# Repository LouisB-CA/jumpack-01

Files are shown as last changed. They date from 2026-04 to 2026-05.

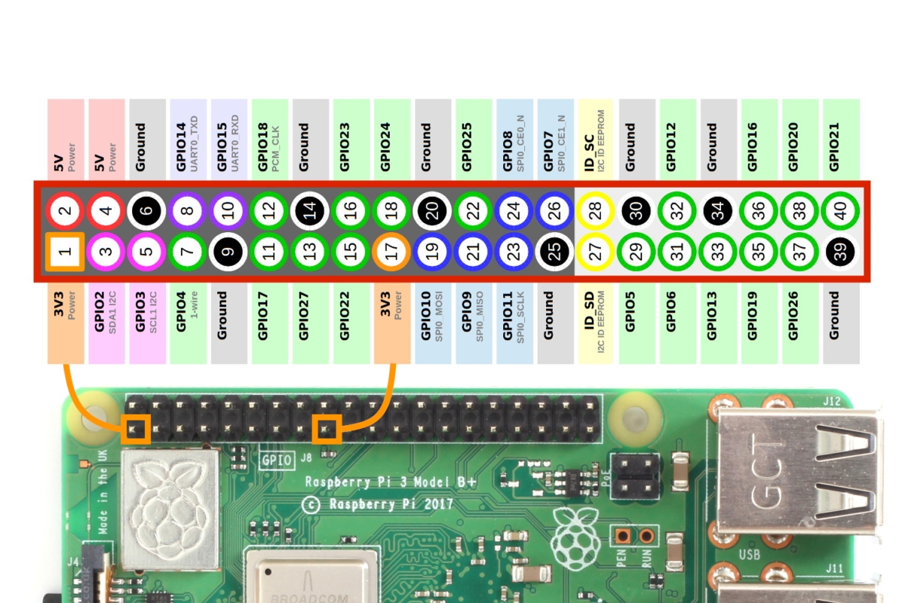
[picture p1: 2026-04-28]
wiring/RPi-GPIO-pinouts-2.png

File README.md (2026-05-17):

# Jumpack-01 battery charger monitor
**Runs on:** [ RPi4, x86 ]

**Languages:** Python, SQL, bash

**Status:** Active

## Hardware Dependencies

| Main Component | Host | Role |
|---|---|---|
| ina228_logger_*.py | RPi4 | polls the sensor, writes SQLite DB |
| monitor-xx.py | x86 | Reads DB, renders real-time plot |

| Support | Host | Role |
|---|---|---|
| simulate_real_time.py | RPi4 | playback |
| dump.py, generate_test_data.py | debugging |

## Description

The INA228 board is used to take 20-bit precision measuements during a battery charging session.
The board communicates with a headless RPi4 via I2C.  

Software is provided to store the data in an SQLite3 database, which can be accessed during the charging operation. 

Software is also provided that can be run from a remote location to plot the data as it is recorded.

The charger is a Coleman lantern wall wart rated at 13.5vdc and 400mA output.

The load is a Cobra Jumpack with input rated at 14vdc and 1A.

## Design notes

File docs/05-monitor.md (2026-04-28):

# How to Monitor the Charging Process

## Rough - needs checking

1. activate the virtual environment - do this as user pi on RPi
2. start the logger in the background - root privileges may be required
3. connect the Coleman power supply and the Jumpack battery
4. create a symlink, charging.db, to the running sqlite3 database
5. on the debian desktop, run 
	`ssh -Y cygnus 'cd ~/prgms/Python/jumpack-01/ && ./.venv/bin/python monitor-02.py'

6. on the RPi, monitor the progress with the *sql_queries.sh* script

## How monitor-02.py works

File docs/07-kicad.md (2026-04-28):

# Version
* The schematic was originally created in KiCad 9.0.7, on 2026-04-26
* At the time, KiCad 10.0.0 was having issues

# Project Library
* All symbols are kept in the project library

# Workflow for KiCad

## Method One uses *sshfs*
* Use a temporary mountpoint on the Debian desktop computer
<br>to mount the remote project directory
```bash
REMOTE="cygnus:prgms/Python/jumpack-01"
MNTPOINT="~/Projects/jumpack"
mkdir -p "$MNTPOINT"
sshfs "$REMOTE" "$MNTPOINT"
```
* Edit the schematic in KiCad on Debian
* Unmount and remove the temporary mountpoint
```bash
# umount usually works, and fuermount3 -u always works
umount "$MNTPOINT"  ||  fusermount3 -u $MNTPOINT"
```

## Method Two uses *git*
* Clone the whole project repo to the Debian desktop computer
* Edit the KiCad schematic
* Commit and push the changes to github

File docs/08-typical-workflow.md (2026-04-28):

# Jumpack-01 battery charger monitor

## In a nutshell
1. Check the wiring
2. Activate the venv
3. Run the ina228 monitor in the background
4. Plug in the charger and the battery
5. Run the monitor program via ssh to plot the data
6. Wait till the current drops to zero

## Typical Workflow
* Do this on the headless RPi4
```bash
PROJECT_DIR="$HOME/prgms/Python/jumpack-01"
cd "$PROJECT_DIR"

source .venv/bin/activate

# Note the use of (1) sudo and (2) the local python
sudo ./.venv/bin/python ina228_logger_v2.py &
```
* Do this on the desktop computer
```bash
ssh -Y cygnus 'cd ~/prgms/Python/jumpack-01/ && python monitor-02.py
```

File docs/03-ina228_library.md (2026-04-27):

# CircuitPython Library for INA228 

* https://docs.circuitpython.org/projects/ina228/en/latest/#
* https://docs.circuitpython.org/projects/ina228/en/stable/index.html

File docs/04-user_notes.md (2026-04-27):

# Workflow
* Activate the virtual environment
* Start the logger program, which must run with root permissions
  <br> `sudo ./.venv/bin/python ./ina228_logger_v2.py &`

* Plug in the Jumpack and the Coleman wall wart

## Options for monitoring the readings
* Include the --verbose flag as an argument to the ina228_logger_v2 python
* Monitor the charging current and voltage with SQL queries
* Use ***waypipe*** to view the plots on a desktop computer
  <br> `waypipe ssh pi@cygnus "cd ~/prgms/Python/jumpack-01 && python monitor-02.py"`

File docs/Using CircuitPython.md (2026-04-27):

Using CircuitPython on a Raspberry Pi 4 requires the [Adafruit Blinka](https://learn.adafruit.com/circuitpython-on-raspberrypi-linux/overview) library, which translates CircuitPython APIs to work on Linux. [1] 
## 1. Pre-requisites
Before running code, you must enable I2C on your Raspberry Pi: [2] 

* Enable I2C: Use the terminal command sudo raspi-config and navigate to Interfacing Options > I2C to enable the bus.
* Install Blinka: Run pip3 install adafruit-blinka to provide the board and busio modules. [1, 3, 4, 5, 6] 

## 2. Basic I2C Scan Example
This "Hello World" of I2C identifies the hexadecimal addresses of all connected devices on the default bus. [7, 8] 

import timeimport board
# Initialize the I2C bus using the board's default SCL and SDA pinsi2c = board.I2C()
while not i2c.try_lock():
    pass
try:
    while True:
        # Scan for devices and print their addresses in hex format
        addresses = [hex(device_address) for device_address in i2c.scan()]
        print("I2C addresses found:", addresses)
        time.sleep(2)finally:
    # Always unlock the bus for other processes when finished
    i2c.unlock()

[9, 10] 
## 3. Reading and Writing to a Device
For more direct interaction with a specific sensor (e.g., at address 0x18), you can use the writeto and readfrom_into methods. [11] 

import boardimport busio
# Create I2C busi2c = busio.I2C(board.SCL, board.SDA)
# Lock the bus before starting a transactionwhile not i2c.try_lock():
    pass
try:
    # Example: Write one byte (0x05) to request data from a specific register
    # Device address is 0x18
    i2c.writeto(0x18, bytes([0x05]))

    # Prepare a buffer to hold the 2 bytes of incoming data
    result = bytearray(2)
    i2c.readfrom_into(0x18, result)
    
    print("Received data:", [hex(b) for b in result])finally:
    i2c.unlock()

[11, 12, 13] 
## Wiring Guide

| Raspberry Pi 4 Pin [14, 15, 16, 17, 18] | I2C Device Pin |
|---|---|
| 3.3V (Pin 1) | VIN / VCC |
| GND (Pin 6/9) | GND |
| SDA (Pin 3 / GPIO 2) | SDA |
| SCL (Pin 5 / GPIO 3) | SCL |

[18, 19, 20] 
Do you need an example for a specific sensor or help troubleshooting a connection error?

[1] [https://learn.adafruit.com](https://learn.adafruit.com/circuitpython-on-raspberrypi-linux/overview)
[2] [https://www.abelectronics.co.uk](https://www.abelectronics.co.uk/kb/article/1/i2c-part-2-enabling-i2c-on-the-raspberry-pi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:,3%20Interface%20Options%20and%20then%20I5%20I2C.)
[3] [https://learn.sparkfun.com](https://learn.sparkfun.com/tutorials/raspberry-pi-spi-and-i2c-tutorial/i2c-on-pi)
[4] [https://openest.io](https://openest.io/non-classe-en/activate-raspberry-pi-4-i2c-bus/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,enable%20the%20i2c%2D1%20bus%20via%20the%20config.)
[5] [https://learn.adafruit.com](https://learn.adafruit.com/adafruit-ltc4316-i2c-address-translator/circuitpython-and-python)
[6] [https://learn.adafruit.com](https://learn.adafruit.com/adafruit-neodriver-i2c-to-neopixel-driver/circuitpython-and-python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,to%20switch%20to%20the%20Adafruit_Extended_Bus%20helper%20library.)
[7] [https://www.youtube.com](https://www.youtube.com/watch?v=0cnNj4qwTAk)
[8] [https://learn.adafruit.com](https://learn.adafruit.com/scanning-i2c-addresses/raspberry-pi)
[9] [https://learn.adafruit.com](https://learn.adafruit.com/scanning-i2c-addresses/circuitpython)
[10] [https://raspberrypi.stackexchange.com](https://raspberrypi.stackexchange.com/questions/132559/circuitpython-interface-with-i2c-device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,when%20ctrl%2Dc%27ing%20out%20of%20the%20loop%20i2c.unlock%28%29)
[11] [https://www.digikey.com](https://www.digikey.com/en/maker/projects/circuitpython-basics-i2c-and-spi/9799e0554de14af3850975dfb0174ae3)
[12] [https://docs.circuitpython.org](https://docs.circuitpython.org/en/10.1.0/shared-bindings/i2ctarget/index.html)
[13] [https://emalliab.wordpress.com](https://emalliab.wordpress.com/2022/01/04/reading-i2c-registers-from-circuitpython/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,=%20reg%20buf.extend%28data%29%20i2cbus.writeto%28addr%2C%20buf%29%20finally:%20i2cbus.unlock%28%29)
[14] [https://learn.adafruit.com](https://learn.adafruit.com/adafruit-neodriver-i2c-to-neopixel-driver/circuitpython-and-python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,NeoPixel%20ground%20to%20driver%20G%20%28black%20wire%29)
[15] [https://www.instructables.com](https://www.instructables.com/Measuring-Temperature-With-I2C-Sensor-LM75A-on-Ras/)
[16] [https://www.halvorsen.blog](https://www.halvorsen.blog/documents/programming/python/resources/powerpoints/Raspberry%20Pi%20and%20CircuitPython.pdf)
[17] [https://roboticsbackend.com](https://roboticsbackend.com/wiringpi-i2c-tutorial-rasperry-pi-adxl345/)
[18] [https://learn.adafruit.com](https://learn.adafruit.com/circuitpython-on-raspberrypi-linux/i2c-sensors-and-devices)
[19] [https://learn.adafruit.com](https://learn.adafruit.com/adafruit-pcf8575/python-circuitpython)
[20] [https://pinout.xyz](https://pinout.xyz/pinout/i2c#:~:text=I2C%20%2D%20Inter%20Integrated%20Circuit%20GPIO%202,fixed%201.8%20k%CE%A9%20pull%2Dup%20resistor%20to%203.3v.)

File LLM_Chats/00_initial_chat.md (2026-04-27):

# Battery Monitor Project - Conversation Summary

## Date
January 15, 2026

## Overview
This conversation established the foundation for a battery charging monitor project. We discussed AI capabilities, project scope, and developed a detailed specification through multiple iterations.

## Key Discussion Points

## Next Steps

1. User will edit Draft 4 specification with hardware details
2. User will run i2cdetect to confirm INA228 address
3. Upload completed specification to project
4. Upload this decisions summary to project
5. Start new chat for Phase 1: Build ina228_test.py

## Important Insights for Future Chats

- This user prefers being asked questions rather than given multiple options
- User values clear version labeling to avoid ambiguity
- User is comfortable with SSH/headless operation
- User has existing scripts on the system (don't break them)
- NeoPixel manager is "the most interesting part" but deliberately saved for later
- User appreciates direct, no-nonsense communication
- Focus on practical solutions over theoretical discussions

## Communication Style Notes

- Avoid bullet points unless explicitly requested or essential for clarity
- Use prose for explanations and reports
- Don't overuse formatting (bold, headers, lists)
- Be specific, not vague (e.g., "Draft 4" not "the latest")
- Ask clarifying questions when specifications are ambiguous
- User will tell you when something needs to be drawn out or explained again

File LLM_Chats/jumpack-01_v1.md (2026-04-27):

# Battery Charging Monitor System - Specification
Version 1.0 -- 2026-01-15

## Context and Purpose

I have a Cobra Model CPP 7500 JumPack battery that I charge using a Coleman 13.5V/600mA wall wart. The charging process takes several hours (maybe up to 10 hours), and I want to collect detailed data about voltage and current throughout the charge cycle so I can analyze it later. I also want to watch the charging process in real-time from my terminal over SSH.

I have developed this specification to help you, Claude, understand the big picture as well as some dtails.  I want to conduct a series of chats to develop a series of programs.  Each program builds on or is nependent on the next.  

If you have any questions, ask for clarification.  

## Hardware Configuration

* Raspberry Pi 4 running raspios 11 bullseye with Python 3.9.2
* Adafruit INA228 breakout board connected via I2C
  - I2C pins are GPIO2 and GPIO3, physical pins 3 and 5
  - address 0x40
  - I have verified the address with CLI commands `i2cdetect -y 1` and `i2cdump -y 1 0x40`
* The INA228 has a R015 (15 mohms) shunt resistor soldered on the breakout board
* The INA228 is wired for high-side measurement, meaning it sits between the charger and the battery positive terminal

* There is one Neopixel LED at GPIO18 (physical pin 12)
  - Don't be concerned if the programs don't use this.  
  - Intended only for that later enhancement, but available.  

## What I Want to Build

This should be three separate Python programs that work together:

### Program 1: Sensor Test (ina228_test.py)

This is just a sanity check before I commit to a long data collection run. When I run it, it should:
- Try to find the INA228 on the I2C bus
- If found, read one sample of raw data from all registers
- Print the raw register values to the terminal with labels
- Convert and display: bus voltage (V), shunt voltage (mV), and current (mA)
- Tell me if it can't find the sensor or if I2C communication fails
- Then exit

This program should be simple enough that if it works, I know the hardware is connected correctly.

### Program 2: Background Data Logger (charge_logger.py)

This is the program that runs for hours collecting data in the background. When I start it, it should:
* Open the INA228 and verify it's responding
* Create a new JSON log file with a timestamp in the filename, like: `charge_log_2026-01-15_14-30-00.json`
* Save this file in directory ./Data/
* Every 2 seconds (adjustable), read voltage and current from the INA228
* Append a JSON object to the log file with: ISO timestamp, human readable time, raw register values, and calculated voltage/current
* If there's an I2C error, log it but keep trying
* Run until I kill it with Ctrl-C or SIGINT, then close the file cleanly
* Print minimal output - just a startup message and maybe a dot every 100 samples so I know it's alive
  - Program will run in the background using nohup with output redirected to a log file

The JSON structure should be an array of measurement objects. Each object needs enough information that I can recalculate anything later if I discover my conversion math was wrong.  The data will be used to predict the time to full charge.  

### Program 3: Real-Time Monitor (charge_monitor.py)

This program watches the log file and shows me what's happening. When I run it:
* Ask me which log file to monitor (or auto-detect the most recent one in the logging directory)
* Open that file and seek to the end
* Every 5 seconds, read any new entries and display the latest values in a clear format:
  - Current time
  - Bus voltage (V, 2 decimal places)
  - Current (mA, 1 decimal place)
  - Power (W, 2 decimal places)
  - Total charge delivered so far (amp-hours, 3 decimal places)
* Handle the case where the logger hasn't written new data yet
* Exit cleanly on Ctrl-C

### Future Enhancement - NeoPixel Manager (optional, not priority)

Eventually I might write a fourth program that manages NeoPixels as a daemon, accepting simple commands like "2 255 0 0" to set pixel 2 to red. But let's save this for dessert - not the immediate priority.

I already have a working python blinky script that flashes various colors on the neopixel. If you want to add neopixel support to any program, be sure to ask me for the blinky script, so you can see what works.  But I think we should not need neopixel support to the first 3 programs.

## Technical Constraints

* I'll be running everything over SSH, so no GUI
* I need to be able to start the logger, disconnect my SSH session, and have it keep running
* The monitor program should work even if I start it hours after the logger started, or if the logger is not running.
* Use a Python virtual environment with dependencies listed in requirements.txt
* Error messages should be clear enough that I can tell what went wrong without reading code

## Development Workflow

We'll build these programs iteratively:
1. Start with Program 1 (sensor test) to verify hardware
2. Once that works, build Program 2 (data logger)
3. Then Program 3 (monitor)
4. NeoPixel manager comes later

When debugging, we'll use version labels like "Version 1", "Version 2", etc. so we know exactly which version we're discussing.  Whenever you give me a first version or a new version, always give it a new identifier (version number) so we can stay on the same page.

We will start a new chat for each of these programs.  Notes and source code from previous chats may be available or can be made available.

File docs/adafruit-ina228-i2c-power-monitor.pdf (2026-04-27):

# Adafruit INA228 I2C Power Monitor

Created by Liz Clark

https://learn.adafruit.com/adafruit-ina228-i2c-power-monitor

Last updated on 2025-08-22 05:00:41 PM EDT

©Adafruit Industries | Page 1 of 28

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
## Table of Contents

Overview
Pinouts
- Power Pins
- I2C Logic Pins
- Input Pins
- VBUS Jumper
- Interrupt Pin
- Power LED
- Address Jumpers
CircuitPython and Python
- CircuitPython Microcontroller Wiring
- Python Computer Wiring
- Python Installation of INA228 Library
- CircuitPython Usage
- Python Usage
- Example Code
Python Docs
Arduino
- Wiring
- Library Installation
- Example Code
Arduino Docs
WipperSnapper
- What is WipperSnapper
- Wiring
- Usage
Downloads
- Files
- Schematic and Fab Print

# Overview

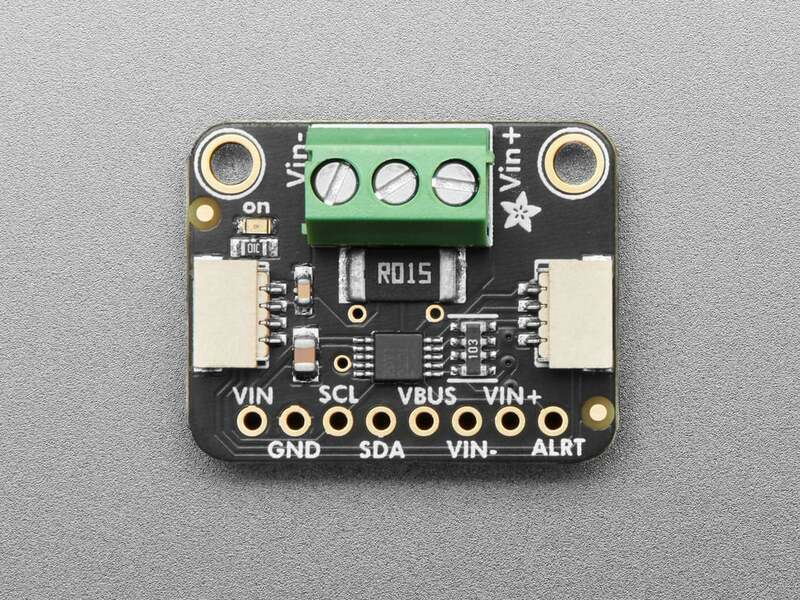
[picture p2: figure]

The INA228 is an amazing power monitoring chip, with best-of-everything support: up to 85VDC common-mode, high or low side measurements, 20-bit (!) ADC for precision measurements from milliamp to Amp, and an I2C interface for easy configuration of alerts, oversampling, gain adjustments and more!

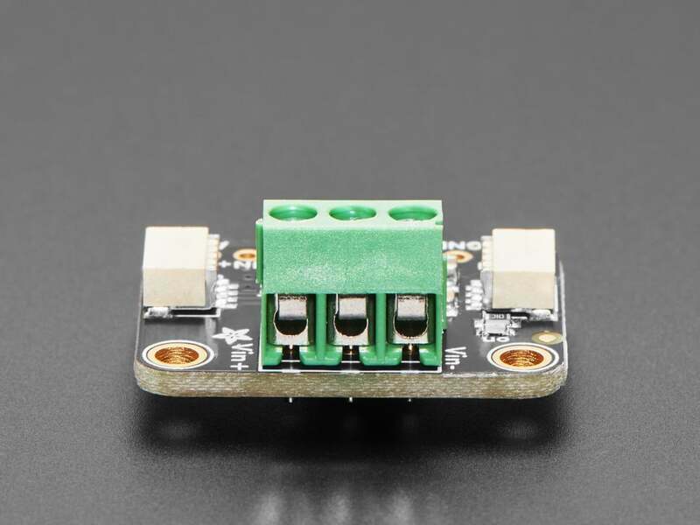
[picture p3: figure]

This breakout board may well be the last current sensing solution you ever need to buy. Not only can it do the work of two multimeters, but it can do it with amazing precision and flexibility. With it you can measure high or low side DC current, the bus voltage, and have it automatically calculate the power. It can do so over impressive voltage, current, and temperature ranges with better than 1% accuracy, all while delivering the data in an easy to use format over I2C.
Works great with any microcontroller that is CircuitPython or Arduino compatible, as well as single board computers such as the Raspberry Pi. It is compatible with 3V or 5V logic and can measure bus voltages up to +85VDC. Note that it is not for use with AC voltages.

Most current-measuring devices operate with some notable constraints that limit what they can be used for. Many are low-side only which can cause issues as the ground reference changes with current. Others like its little sister the INA219B avoid this by measuring on the high side but need to change their shunt resistor to measure different current ranges. The INA228 avoids these limitations, and with the precision 15 milliohm shunt resistor on board, it can be used to measure as much as +85V at up to 10A (~10uA per LSB) or 2.75A (~2.5uA per LSB) Continuous on either the high or low side. Wow!

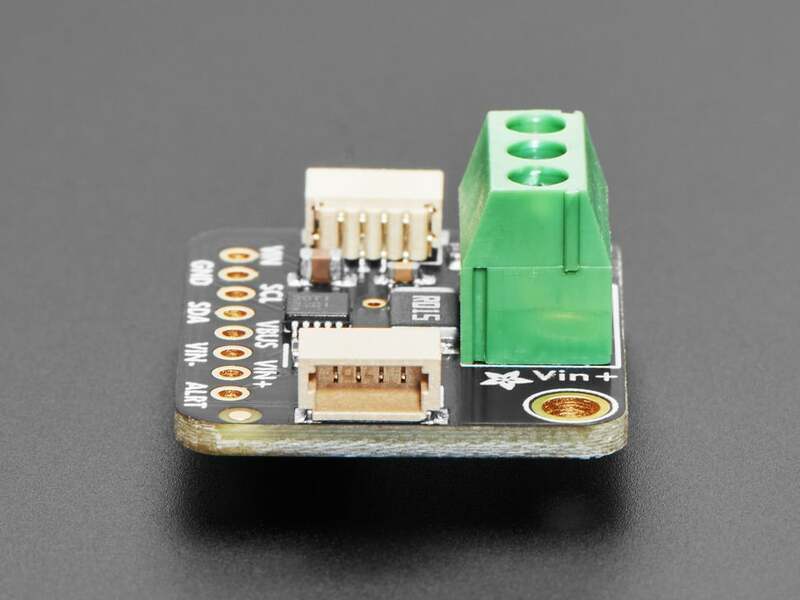
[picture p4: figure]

The voltage across the integrated 15 milliohm (.015 ohms!), 0.1% shunt resistor is measured by the internal 20 bit ADC, allowing for measurements over the impressive current range with a resolution of 10uA per LSB in high current measurement mode or 2.5uA per LSB in low current measurement mode.

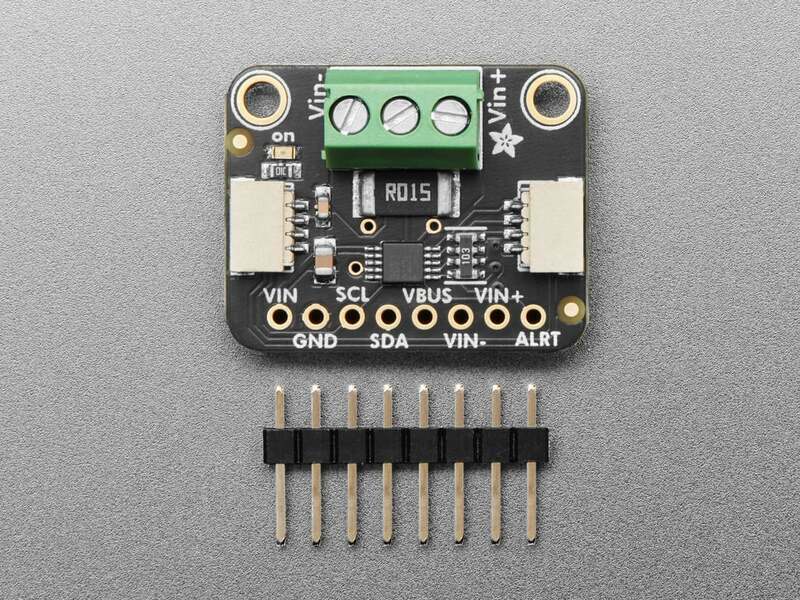
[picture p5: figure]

To measure low-side, connect VIN- to ground and VIN+ to your load's lowest potential. VBUS should connect to the highest project voltage, up to 85V. To measure high-side, connect VIN+ to VBUS to the highest project voltage, and VIN- to the load's highest potential. In high-side measurement, which is most common, you can simplify connecting V+ to VBUS by soldering closed the back jumper.

This comes as a fully assembled breakout board with a 3.5mm terminal block and header. Some light soldering is required to attach the header for use in a breadboard.

# Pinouts

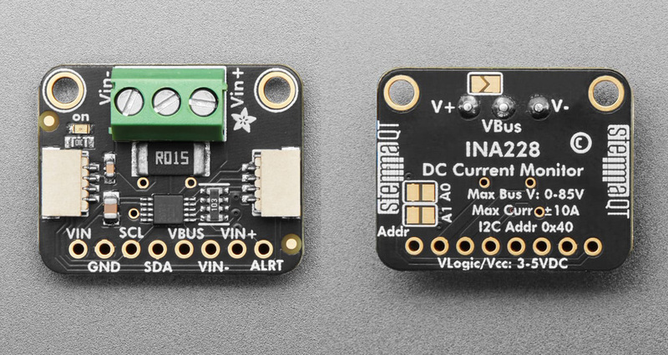
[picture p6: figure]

The default I2C address is 0x40.

## Power Pins

VIN - this is the power pin. It can be powered by 3V or 5V. Give it the same power as the logic level of your microcontroller - e.g. for a 5V micro like Arduino, use 5V.
GND - common ground for power and logic.

## I2C Logic Pins

SCL - I2C clock pin, connect to your microcontroller's I2C clock line. This pin can use 3-5V logic, and there's a 10K pullup on this pin.
SDA - I2C data pin, connect to your microcontroller's I2C data line. This pin can use 3-5V logic, and there's a 10K pullup on this pin.
STEMMA QT (https://learn.adafruit.com/introducing-adafruit-stemma-qt) (https://adafru.it/Ft4) - These connectors allow you to connect to development boards with STEMMA QT (Qwiic) connectors or to other things with various associated accessories (https://www.adafruit.com/?q=JST%20SH%204) (https://adafru.it/Ft6).

## Input Pins

The pins are in a low side measurement configuration by default. They are available along the bottom edge of the board and the terminal block on the top edge of the board.

VIN+ - Positive input pin.
VIN- - Negative input pin.

•

•

•

•

•

•
•

VBUS - Bus voltage input pin.

To measure low-side, Connect VIN- to ground and VIN+ to your load's lowest potential. VBUS should connect to the highest project voltage, up to 85V.
To measure high-side, connect VIN+ to VBUS to the highest project voltage, and VIN-to the load's highest potential.

## VBUS Jumper

On the back of the board, above the VIN+ and VBUS pins, is the VBUS jumper. This jumper connects or disconnects VBUS from VIN+. When the jumper is open (default), it configures the board for low side measurement. When the jumper is soldered closed, it configures the board for high side measurement.

## Interrupt Pin

ALRT - The alert/interrupt pin. The default state is active low.

## Power LED

Power LED - In the upper left corner, above the STEMMA connector, on the front of the board, is the power LED, labeled on. It is the green LED.

## Address Jumpers

On the back of the board are two address jumpers, labeled A0 and A1, above the Addr label on the board silk. These jumpers allow you to chain up to 4 of these boards on the same pair of I2C clock and data pins. To do so, you solder the jumpers "closed" by connecting the two pads.
The default I2C address is 0x40. The table below lists the jumper combinations and the associated I2C addresses.

•

•

•

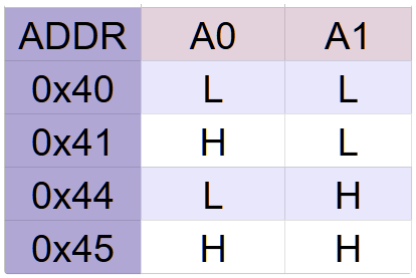
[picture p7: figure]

# CircuitPython and Python

It's easy to use the INA228 with Python or CircuitPython, and the Adafruit_CircuitPython_INA228 (https://github.com/adafruit/Adafruit_CircuitPython_INA228) (https://adafru.it/1ae7) module. This module allows you to easily write Python code to monitor high or low side power measurements. You can use this driver with any CircuitPython microcontroller board or with a computer that has GPIO and Python thanks to Adafruit_Blinka, our CircuitPython-for-Python compatibility library (https://learn.adafruit.com/circuitpython-on-raspberrypi-linux) (https://adafru.it/BSN).

## CircuitPython Microcontroller Wiring

First wire up the monitor to your board exactly as follows. The following is the monitor wired to a Feather RP2040 using the STEMMA connector for low side monitoring:

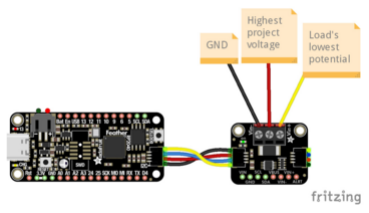
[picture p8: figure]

Board STEMMA 3V to breakout VIN (red wire)
Board STEMMA GND to breakout GND (black wire)
Board STEMMA SCL to breakout SCL (yellow wire)
Board STEMMA SDA to breakout SDA (blue wire)
Breakout Vin- to GND (black wire) Breakout VBus to highest potential voltage (red wire)
Breakout Vin+ to load's lowest potential (yellow wire)

Here is the monitor wired to a Feather RP2040 using the STEMMA connector for high side monitoring:

Board STEMMA 3V to breakout VIN (red wire)
Board STEMMA GND to breakout GND (black wire)
Board STEMMA SCL to breakout SCL (yellow wire)
Board STEMMA SDA to breakout SDA (blue wire)
Breakout Vin- to load's highest potential (yellow wire)
Breakout VBus to breakout Vin+ (red wire) Breakout Vin+ to highest project voltage (red wire)

The following is the monitor wired to a Feather RP2040 using a solderless breadboard for low side monitoring:

Board 3.3V to breakout VIN (red wire) Board GND to breakout GND (black wire) Board SCL to breakout SCL (yellow wire) Board SDA to breakout SDA (blue wire) Breakout VIN- to GND (black wire) Breakout VBUS to highest potential voltage (red wire)
Breakout VIN+ to load's lowest potential (yellow wire)

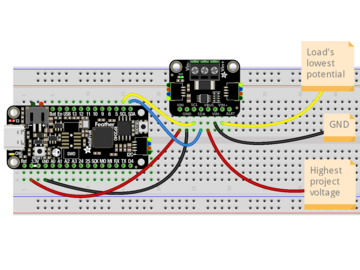
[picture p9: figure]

Here is the monitor wired to a Feather RP2040 using a solderless breadboard for high side monitoring:

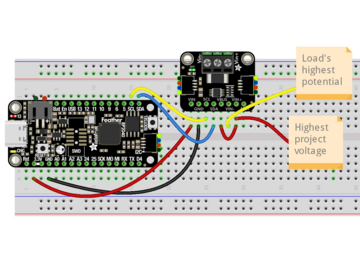
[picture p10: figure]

Board 3.3V to breakout VIN (red wire) Board GND to breakout GND (black wire) Board SCL to breakout SCL (yellow wire) Board SDA to breakout SDA (blue wire) Breakout VIN- to load's highest potential (yellow wire)
Breakout VBUS to breakout VIN+ (red wire)
Breakout VIN+ to highest project voltage (red wire)

## Python Computer Wiring

Since there are dozens of Linux computers/boards you can use, we will show wiring for Raspberry Pi. For other platforms, please visit the guide for CircuitPython on Linux to see whether your platform is supported (https://learn.adafruit.com/circuitpython-on-raspberrypi-linux) (https://adafru.it/BSN).
Here's the Raspberry Pi wired with I2C using the STEMMA connector for low side monitoring:

Pi 3.3V to breakout VIN (red wire) Pi GND to breakout GND (black wire) Pi SCL to breakout SCL (yellow wire) Pi SDA to breakout SDA (blue wire) Breakout VIN- to GND (black wire) Breakout VBUS to highest potential voltage (red wire)
Breakout VIN+ to load's lowest potential (yellow wire)

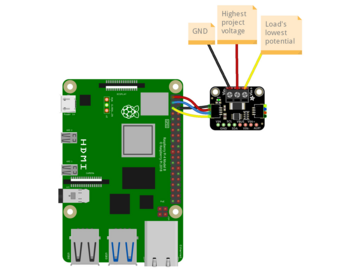
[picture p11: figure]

Here's the wiring using the STEMMA connector for high side monitoring:

For high side monitoring, you can solder the VBus jumper closed on the back of the breakout to simplify your wiring.

Pi 3.3V to breakout VIN (red wire) Pi GND to breakout GND (black wire) Pi SCL to breakout SCL (yellow wire) Pi SDA to breakout SDA (blue wire) Breakout Vin- to load's highest potential (yellow wire)
Breakout VBus to breakout Vin+ (red wire) Breakout Vin+ to highest project voltage (red wire)

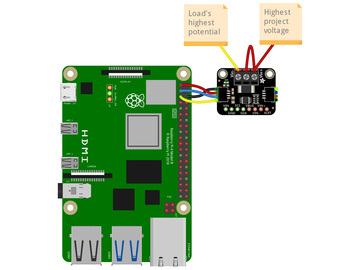
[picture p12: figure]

Here's the Raspberry Pi wired with I2C using a solderless breadboard for low side monitoring:

Pi 3.3V to breakout VIN (red wire) Pi GND to breakout GND (black wire) Pi SCL to breakout SCL (yellow wire) Pi SDA to breakout SDA (blue wire) Breakout VIN- to GND (black wire) Breakout VBUS to highest potential voltage (red wire)
Breakout VIN+ to load's lowest potential (yellow wire)

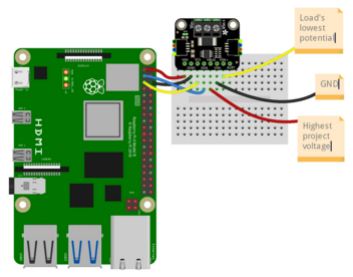
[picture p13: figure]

Here's the wiring using a solderless breadboard for high side monitoring:

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

## Python Installation of INA228 Library

You'll need to install the Adafruit_Blinka library that provides the CircuitPython support in Python. This may also require enabling I2C on your platform and verifying you are running Python 3. Since each platform is a little different, and Linux changes often, please visit the CircuitPython on Linux guide to get your computer
ready (https://learn.adafruit.com/circuitpython-on-raspberrypi-linux) (https://adafru.it/BSN)!
Once that's done, from your command line run the following command:

pip3 install adafruit-circuitpython-ina228

If your default Python is version 3 you may need to run 'pip' instead. Just make sure you aren't trying to use CircuitPython on Python 2.x, it isn't supported!

## CircuitPython Usage

To use with CircuitPython, you need to first install the Adafruit_CircuitPython_INA228 library, and its dependencies, into the lib folder on your CIRCUITPY drive. Then you need to update code.py with the example script.
Thankfully, we can do this in one go. In the example below, click the Download Project Bundle button below to download the necessary libraries and the code.py file in a zip file. Extract the contents of the zip file, and copy the entire lib folder and the code.py file to your CIRCUITPY drive.
Your CIRCUITPY/lib folder should contain the following folders and file:

adafruit_bus_device/
adafruit_register/
adafruit_ina228.mpy

For high side monitoring, you can solder the VBus jumper closed on the back of the breakout to simplify your wiring.

•

•
•
•

## Python Usage

Once you have the library | pip3 | installed on your computer, copy or download the
following example to your computer, and run the following, replacing code.py with whatever you named the file:

python3 code.py

## Example Code

If running CircuitPython: Once everything is saved to the CIRCUITPY drive, connect to the serial console (https://learn.adafruit.com/welcome-to-circuitpython/kattni-connecting-to-the-serial-console) (https://adafru.it/Bec) to see the data printed out!
If running Python: The console output will appear wherever you are running Python.

# SPDX-FileCopyrightText: Copyright (c) 2025 Liz Clark for Adafruit Industries #

# SPDX-License-Identifier: MIT

import time

import board

import adafruit_ina228

i2c = board.I2C()
ina228 = adafruit_ina228.INA228(i2c)
print("Adafruit INA228 Test")

print(f"Bus conversion time: {ina228.bus_voltage_conv_time} microseconds") print(f"Shunt conversion time: {ina228.shunt_voltage_conv_time} microseconds") print(f"Samples averaged: {ina228.averaging_count}")

while True:
print("\nCurrent Measurements:")
print(f"Current: {ina228.current:.2f} mA")
print(f"Bus Voltage: {ina228.bus_voltage:.2f} V") print(f"Shunt Voltage: {ina228.shunt_voltage*1000:.2f} mV") print(f"Power: {ina228.power:.2f} mW")
print(f"Energy: {ina228.energy:.2f} J") print(f"Temperature: {ina228.die_temperature:.2f} °C") time.sleep(1)

First, the sensor is instantiated over I2C. Then, in the loop, the measurements for current, bus voltage, shunt voltage, power, energy and temperature are printed to the serial console.

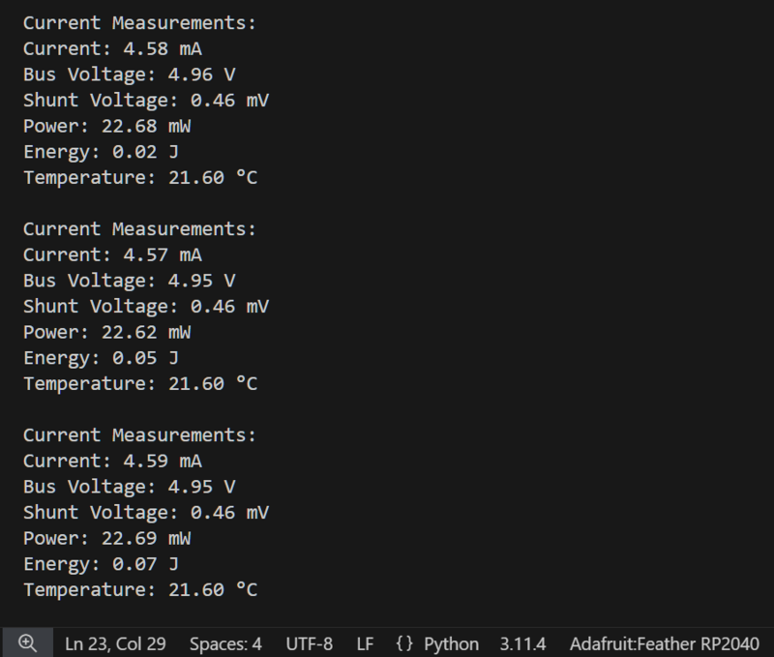
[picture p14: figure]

# Python Docs

Python Docs (https://adafruit-circuitpython-ina228.readthedocs.io/en/latest/) (https://adafru.it/1ae0)

# Arduino

Using the INA228 breakout with Arduino involves wiring up the breakout to your Arduino-compatible microcontroller, installing the Adafruit_INA228 (https://github.com/adafruit/Adafruit_INA228) (https://adafru.it/1ae8) library, and running the provided example code.

## Wiring

Wire as shown for a 5V board like an Uno. If you are using a 3V board, like an Adafruit Feather, wire the board's 3V pin to the sensor VIN.
Here is an Adafruit Metro wired up to the breakout using the STEMMA QT connector for low side monitoring:

Board 5V to breakout VIN (red wire) Board GND to breakout GND (black wire) Board SCL to breakout SCL (yellow wire) Board SDA to breakout SDA (blue wire) Breakout Vin- to GND (black wire) Breakout VBus to highest potential voltage (red wire)
Breakout Vin+ to load's lowest potential (yellow wire)

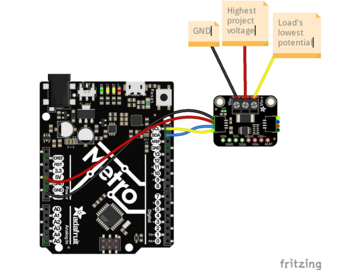
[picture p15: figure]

Here is an Adafruit Metro wired up to the breakout using the STEMMA QT connector for high side monitoring:

Board 5V to breakout VIN (red wire) Board GND to breakout GND (black wire) Board SCL to breakout SCL (yellow wire) Board SDA to breakout SDA (blue wire) Breakout Vin- to load's highest potential (yellow wire)
Breakout VBus to breakout Vin+ (red wire) Breakout Vin+ to highest project voltage (red wire)

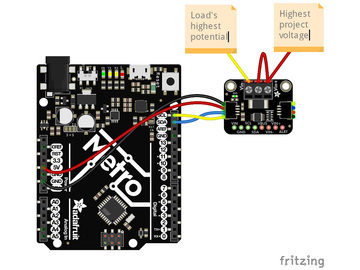
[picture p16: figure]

Here is an Adafruit Metro wired up using a solderless breadboard for low side monitoring:

Board 5V to breakout VIN (red wire) Board GND to breakout GND (black wire) Board SCL to breakout SCL (yellow wire) Board SDA to breakout SDA (blue wire) Breakout VIN- to GND (black wire) Breakout VBUS to highest potential voltage (red wire)
Breakout VIN+ to load's lowest potential (yellow wire)

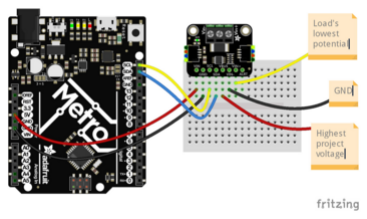
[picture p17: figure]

Here is an Adafruit Metro wired up using a solderless breadboard for high side monitoring:

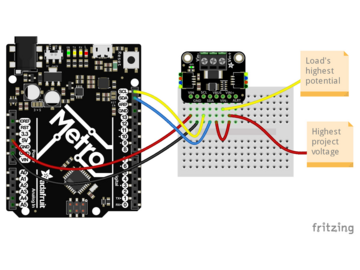
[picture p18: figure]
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

## Library Installation

You can install the Adafruit_INA228 library for Arduino using the Library Manager in the Arduino IDE.

Click the Manage Libraries ... menu item, search for Adafruit_INA228, and select the Adafruit INA228 library:

For high side monitoring, you can solder the VBus jumper closed on the back of the breakout to simplify your wiring.

If asked about dependencies, click "Install all".

If the "Dependencies" window does not come up, then you already have the

If the dependencies are already installed, you must make sure you update them through the Arduino Library Manager before loading the example!

while (1)
;
}
Serial.println("Found INA228 chip");
// set shunt resistance and max current ina228.setShunt(0.015, 10.0);

ina228.setAveragingCount(INA228_COUNT_16);
uint16_t counts[] = {1, 4, 16, 64, 128, 256, 512, 1024}; Serial.print("Averaging counts: "); Serial.println(counts[ina228.getAveragingCount()]);

// set the time over which to measure the current and bus voltage ina228.setVoltageConversionTime(INA228_TIME_150_us); Serial.print("Voltage conversion time: ");
switch (ina228.getVoltageConversionTime()) {
case INA228_TIME_50_us:
Serial.print("50");
break;
case INA228_TIME_84_us:
Serial.print("84");
break;
case INA228_TIME_150_us:
Serial.print("150");
break;
case INA228_TIME_280_us:
Serial.print("280");
break;
case INA228_TIME_540_us:
Serial.print("540");
break;
case INA228_TIME_1052_us:
Serial.print("1052");
break;
case INA228_TIME_2074_us:
Serial.print("2074");
break;
case INA228_TIME_4120_us:
Serial.print("4120");
break;
}
Serial.println(" uS");

ina228.setCurrentConversionTime(INA228_TIME_280_us); Serial.print("Current conversion time: ");
switch (ina228.getCurrentConversionTime()) {
case INA228_TIME_50_us:
Serial.print("50");
break;
case INA228_TIME_84_us:
Serial.print("84");
break;
case INA228_TIME_150_us:
Serial.print("150");
break;
case INA228_TIME_280_us:
Serial.print("280");
break;
case INA228_TIME_540_us:
Serial.print("540");
break;
case INA228_TIME_1052_us:
Serial.print("1052");
break;
case INA228_TIME_2074_us:
Serial.print("2074");
break;
case INA228_TIME_4120_us:
Serial.print("4120");

break;
}
Serial.println(" uS");

// default polarity for the alert is low on ready, but // it can be inverted!
// ina228.setAlertPolarity(1);
}

void loop() {

// by default the sensor does continuous reading, but
// we can set to triggered mode. to do that, we have to set
// the mode to trigger a new reading, then wait for a conversion // either by checking the ALERT pin or reading the ready register // ina228.setMode(INA228_MODE_TRIGGERED);
// while (!ina228.conversionReady())
// delay(1);

Serial.print("Current: "); Serial.print(ina228.getCurrent_mA()); Serial.println(" mA");

Serial.print("Bus Voltage: "); Serial.print(ina228.getBusVoltage_V()); Serial.println(" V");

Serial.print("Shunt Voltage: "); Serial.print(ina228.getShuntVoltage_mV()); Serial.println(" mV");

Serial.print("Power: ");
Serial.print(ina228.getPower_mW()); Serial.println(" mW");

Serial.print("Energy: ");
Serial.print(ina228.readEnergy()); Serial.println(" J");

Serial.print("Charge: ");
Serial.print(ina228.readCharge()); Serial.println(" C");

Serial.print("Temperature: "); Serial.print(ina228.readDieTemp()); Serial.println(" *C");

Serial.println();
delay(1000);
}

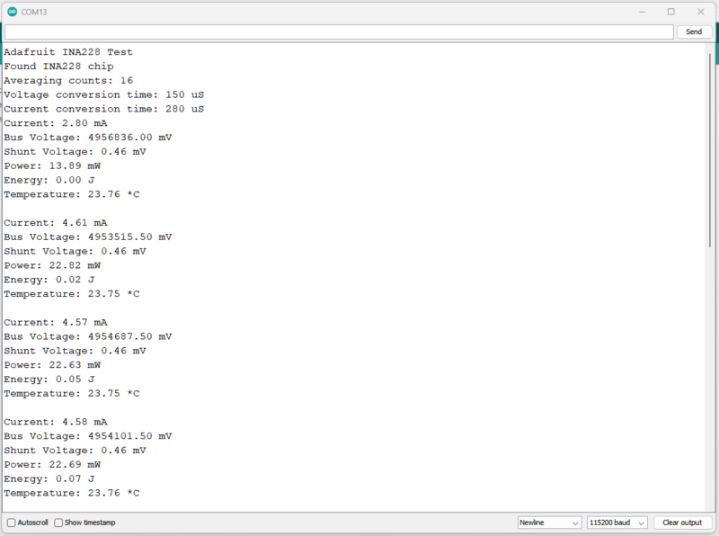
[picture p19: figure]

Upload the sketch to your board and open up the Serial Monitor (Tools -> Serial Monitor) at 115200 baud. You'll see the INA228 recognized over I2C. Then, your connected project's current, bus voltage, shunt voltage, power and energy measurements are printed out every second, along with the INA228's temperature reading in Celsius.

# Arduino Docs

Arduino Docs (https://adafruit.github.io/Adafruit_INA228/html/index.html) (https://adafru.it/1adZ)

# WipperSnapper

## What is WipperSnapper

WipperSnapper is a firmware designed to turn any WiFi-capable board into an Internet-of-Things device without programming a single line of code. WipperSnapper connects to Adafruit IO (https://io.adafruit.com/) (https://adafru.it/fsU), a web platform designed (by
Adafruit! (https://www.adafruit.com/about) (https://adafru.it/Bo5)) to display, respond, and interact with your project's data.
Simply load the WipperSnapper firmware onto your board, add credentials, and plug it into power. Your board will automatically register itself with your Adafruit IO account. From there, you can add components to your board such as buttons, switches, potentiometers, sensors, and more! Components are dynamically added to hardware, so you can immediately start interacting, logging, and streaming the data your projects produce without writing code.
If you've never used WipperSnapper, click below to read through the quick start guide before continuing.
Quickstart: Adafruit IO
WipperSnapper (https://learn.adafruit.com/quickstart-adafruit-io-wippersnapper)
https://adafru.it/Vfd

## Wiring

First, wire up an INA228 to your board exactly as follows. You can use a Stemma QT cable to make wiring the boards together easier if you prefer, but here is an example of the INA228 wired to an Adafruit ESP32 Feather V2 (https://www.adafruit.com/product/5400) (http://adafru.it/5400) using I2C via Dupont Jumper Wires (https://www.adafruit.com/search?q=jumper+wires) (https://adafru.it/1ahv) mounted in one of
our prototyping breadboards (https://www.adafruit.com/product/4539) (http://adafru.it/4539):

Board 5V to breakout VIN (red wire) Board GND to breakout GND (black wire) Board SCL to breakout SCL (yellow wire) Board SDA to breakout SDA (blue wire) Breakout Vin- to load's highest potential (red/white banded wire)
Breakout VBus to breakout Vin+ (pink wire)
Breakout Vin+ to highest project voltage (red wire)
Load GND/lowest potential to Shared board GND
If you wish to measure the low-side of your load/circuit, instead of the high-side, then follow the low-side wiring instructions on this guides Arduino (https://learn.adafruit.com/adafruit-ina228-i2c-power-monitor/arduino) (https://adafru.it/1aqq) page.

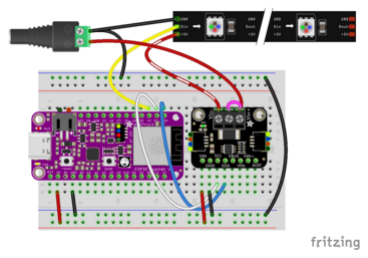
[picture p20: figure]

## Usage

Connect your board to Adafruit IO Wippersnapper and navigate to the WipperSnapper board list (https://io.adafruit.com/wippersnapper) (https://adafru.it/TAu).
On this page, select the WipperSnapper board you're using to be brought to the board's interface page.

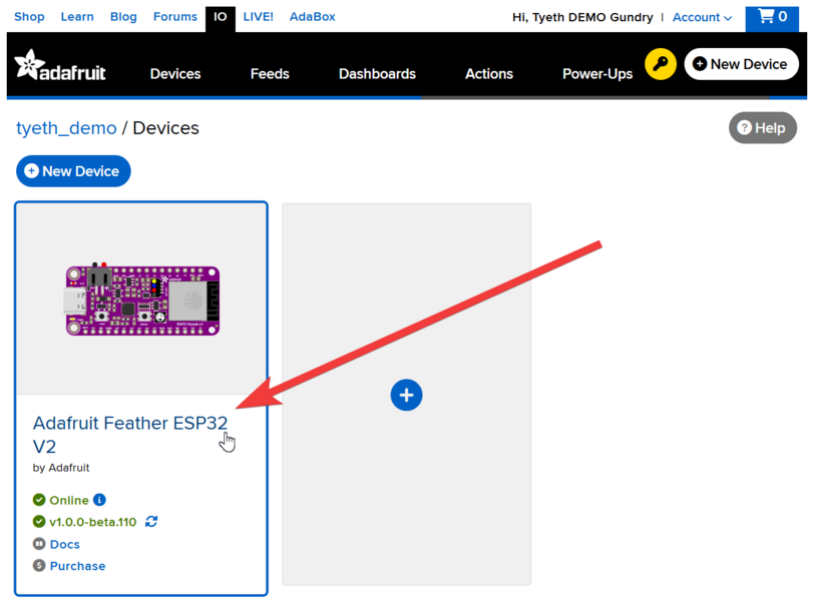
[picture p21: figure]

If you do not see your board listed here - you need to connect your board to Adafruit IO (https://learn.adafruit.com/quickstart-adafruit-io-wippersnapper) (https://adafru.it/Vfd) first.

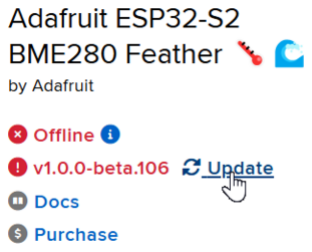
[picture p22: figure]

On the device page, quickly check that you're running the latest version of the WipperSnapper firmware and that your device is Online.
The device tile on the left indicates the version number of the firmware running on the connected board.

If the firmware version is green with a checkmark - continue with this guide.
If the firmware version is red with an exclamation mark "!" - update to the latest WipperSnapper firmware (https://learn.adafruit.com/quickstart-adafruit-io-wippersnapper) (https://adafru.it/Vfd) on your board before continuing.

Next, make sure the sensor is plugged into your board and click the I2C Scan button.

You should see the INA228's default I2C address of | 0x40 | pop-up in the I2C scan list.

With the sensor detected in an I2C scan, you're ready to add the sensor to your

Click the New Component button or the + button to bring up the component picker.

First, double-check the connection and/or wiring between the sensor

Then, reset the board and let it re-connect to Adafruit IO WipperSnapper.

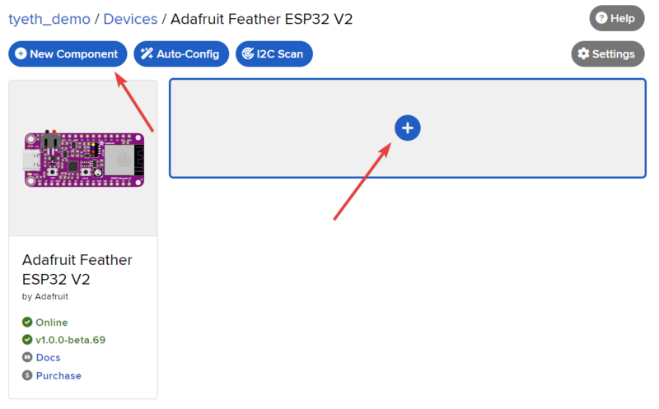
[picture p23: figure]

Adafruit IO supports a large amount of components. To quickly find your sensor,
type | INA228 | into the search bar, then select the INA228 component

On the component configuration page, the INA228's sensor address should be listed along with the sensor's settings.
The Send Every option is specific to each sensor's measurements. This option will tell the Feather how often it should read from the INA228 sensor and send the data to Adafruit IO. Measurements can range from every 30 seconds to every 24 hours.
For this example, set the Send Every interval to every 30 seconds.

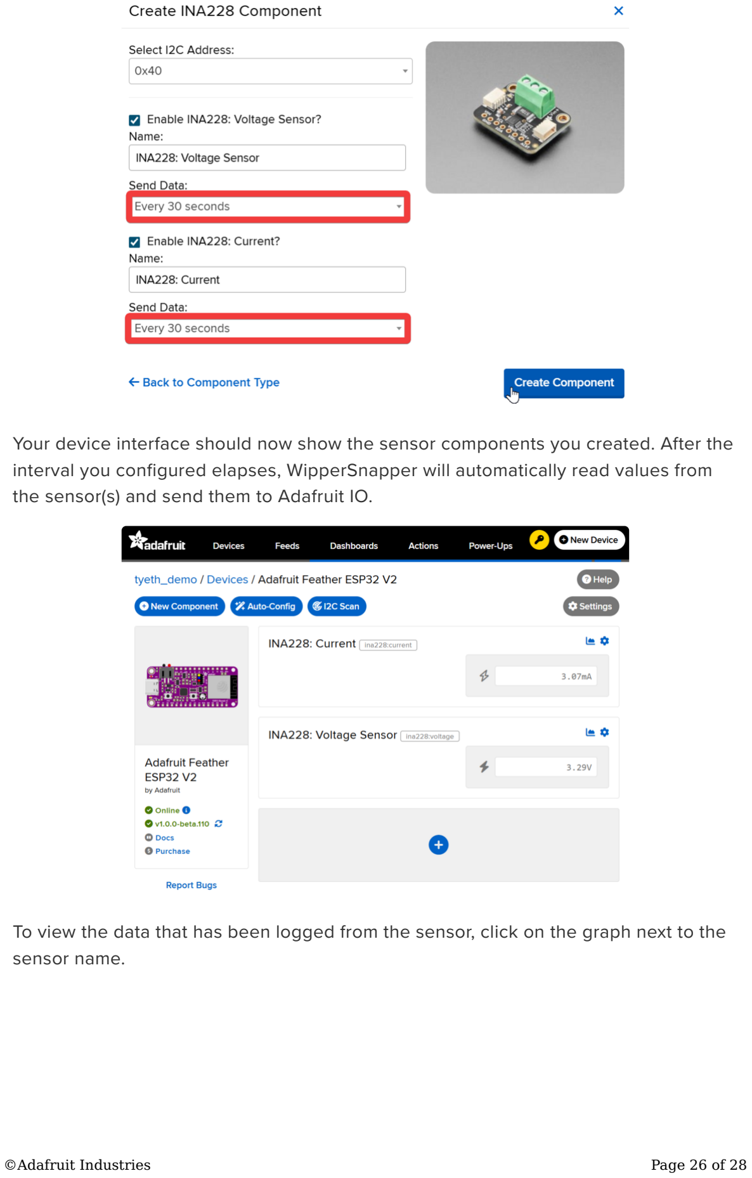
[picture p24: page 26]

Your device interface should now show the sensor components you created. After the interval you configured elapses, WipperSnapper will automatically read values from the sensor(s) and send them to Adafruit IO.

To view the data that has been logged from the sensor, click on the graph next to the sensor name.

Here you can see the feed history and edit things about the feed such as the name, privacy, webhooks associated with the feed and more. If you want to learn more about how feeds work, check out this page (https://learn.adafruit.com/all-the-internet-of-things-episode-four-adafruit-io/advanced-feeds) (https://adafru.it/10aZ).

# Downloads

## Files

INA228 Datasheet (https://cdn-learn.adafruit.com/assets/assets/000/125/556/original/ina228.pdf?1698092011) (https://adafru.it/1ae9)
EagleCAD PCB Files on GitHub (https://github.com/adafruit/Adafruit-INA228-PCB) (https://adafru.it/1aea)
Fritzing object in the Adafruit Fritzing Library (https://github.com/adafruit/Fritzing-Library/blob/master/parts/Adafruit%20INA228%20I2C%20Power%20Monitor.fzpz) (https://adafru.it/1aeb)

•
•
•

## Schematic and Fab Print

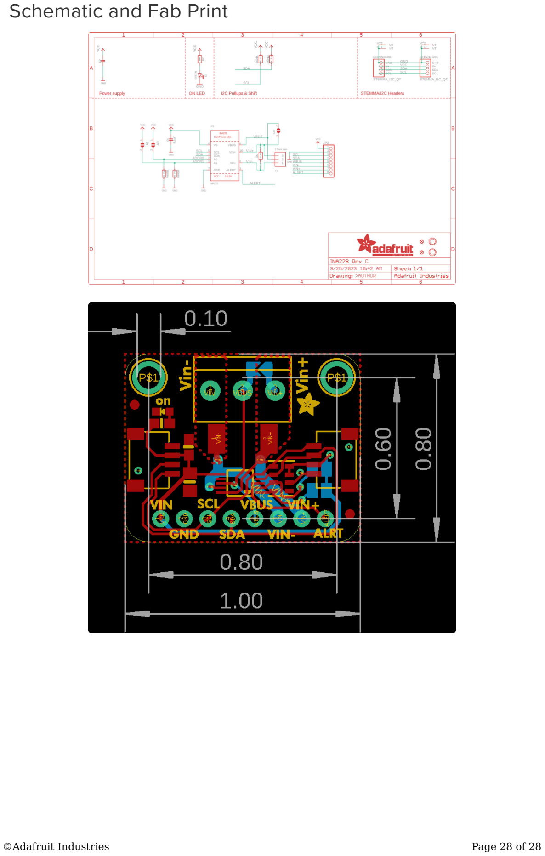
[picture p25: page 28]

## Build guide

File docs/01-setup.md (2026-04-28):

# Best Practice
* Modern (2026) best practice is to always use a virtual environment.

# Initial Setup Considerations for RaspiOS 13
* There were changes to the OS that rendered the old venv stale.
<br>so this setup explicitly deletes the old venv

# Create a project directory
```bash
cd ~
PROJECT_DIR="$HOME/prgms/Python/jumpack-01"

# Create a project directory
mkdir -p "$PROJECT_DIR"
cd "$PROJECT_DIR"
```

## Remove and re-initialize the virtual environment
```bash
PROJECT_DIR="$HOME/prgms/Python/jumpack-01"
cd "$PROJECT_DIR"
rm -rf .venv

# Create a virtual environment
python3 -m venv .venv

# Activate it
source .venv/bin/activate

# Now install the libraries
pip install --upgrade pip
pip install --upgrade adafruit-circuitpython-ina228
pip install --upgrade matplotlib

# Print message
echo -e "\n\nDon't forget to use \`sudo ./.venv/bin/python ina228_test.py\` to execute!\n"

```

## Group *gpio* instead of *sudo*
* If the user is a member of group *gpio*, sudoer privileges are not required.
* First, see if the user is already a member
```bash
# Do this as a plain user
groups | tr ' ' '\' | grep gpio\|i2c\|spi
```
If the output is "gpio", "i2c" and "spi" you don't need sudoer privileges, you can use
```bash
python ina228_test.py
```
* To become a member, do this
```bash
sudo usermod -aG pi gpio,i2c,spi
```

## Activate I2C and SPI
* The INA228 communicates via I2C
* Neopixels require SPI.
* Do this as a plain user to check that these are active
```bash
raspi-config nonint get_i2c   # returns 0 = enabled, 1 = disabled
raspi-config nonint get_spi   # returns 0 = enabled, 1 = disabled
```

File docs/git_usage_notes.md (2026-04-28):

# Git Usage Notes
## Preliminary
```bash
# Check you default branch name
git config --global --get init.defaultBranch		# expect main, not master

# Check other configuration parameters
git config --global --list --show-origin

# Set default branch to main
git config --global init.defaultBranch main
```

## Create the repo
```bash
# 1. Initialize the repo
git init

# 2. Stage everything
git add .

# 3. First commit
git commit -m "Initial commit"

# 4. Create the remote repo on GitHub and push
gh repo create jumpack-01 --public --source=. --remote=origin --push

```

## If the repo already exists on github
```bash
git remote add origin https://github.com/LouisB-CA/jumpack-01.git
git branch -M main
git push -u origin main
```

## If you get HEAD -> master instead of HEAD -> main
```bash
# Rename the local branch
git branch -m master main

# Push the new branch name and reset the upstream tracking
git push origin -u main

# Set the main branch to be default
gh api repos/LouisB-CA/jumpack-01 --method PATCH --field default_branch=main

# Delete the master branch
git push origin --delete master

```

## Updating the repo
```bash
# See what's modified
git status

# Stage all modified files
git add .

# Or stage specific files
git add <filename>

# Then commit
git commit -m "Update docs"

# Push
git push
```

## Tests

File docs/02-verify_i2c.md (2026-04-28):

# I2C Command Reference for INA228
* This doc assumes the I2C address of the INA228 is 0x40

## Verify I2C is enabled
```bash
raspi-config nonint get_i2c   # returns 0 = enabled, 1 = disabled
```

## Using i2cdetect to Find Device Address
```bash
i2cdetect -y 1
```

This scans I2C bus 1 and shows a grid of addresses. Your INA228 will show up as a two-digit hex number (like `40`, `45`, etc.) in the grid. Everything else will show `--`.

The `-y` flag means "yes, just do it" (skips the warning prompt).

## What You'll See
```
     0  1  2  3  4  5  6  7  8  9  a  b  c  d  e  f
00:          -- -- -- -- -- -- -- -- -- -- -- -- -- 
10: -- -- -- -- -- -- -- -- -- -- -- -- -- -- -- -- 
20: -- -- -- -- -- -- -- -- -- -- -- -- -- -- -- -- 
30: -- -- -- -- -- -- -- -- -- -- -- -- -- -- -- -- 
40: 45 -- -- -- -- -- -- -- -- -- -- -- -- -- -- -- 
50: -- -- -- -- -- -- -- -- -- -- -- -- -- -- -- -- 
60: -- -- -- -- -- -- -- -- -- -- -- -- -- -- -- -- 
70: -- -- -- -- -- -- -- --
```

In this example, the device is at address `0x45`.

## Other Useful I2C Commands

### List Available I2C Buses
```bash
i2cdetect -l
```

### Read Single Byte from Register
```bash
# Read from register 0x00 on device at 0x45
i2cget -y 1 0x40 0x00
```

### Dump All Registers
```bash
# Shows first 256 bytes of register space
i2cdump -y 1 0x40
```

### Write to Register (Use Carefully)
```bash
# Write 0xFF to register 0x00 - can misconfigure the chip
i2cset -y 1 0x40 0x00 0xFF
```

## Verifying INA228 Specifically

The `i2cdump` command is most useful for verification. The INA228 has specific registers at known addresses:

- **Register 0x00**: Configuration
- **Register 0x01**: ADC Configuration  
- **Register 0x04**: Shunt Voltage
- **Register 0x05**: Bus Voltage
- **Register 0x07**: Current

If `i2cdump -y 1 0x40` shows reasonable hex values (not all `FF` or all `00`), the chip is alive and responding.

## Quick Verification Steps

1. Run `i2cdetect -y 1` to confirm device address
2. Run `i2cdump -y 1 [address]` to verify chip is responding
3. Look for non-zero, non-FF values in the dump output

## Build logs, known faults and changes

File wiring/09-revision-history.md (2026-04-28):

# Revision History

## ina228_logger series
### ina228_logger_02.py
* Runs well, but without LEDs

### ina228_logger_03.py
* Added code for an LED on GPIO23

## monitor series
### monitor-02.py
* Runs well to monitor the sqlite3 charging.db file

## Wiring diagrams
### wiring-diagram-02
* shows green LED as spare
* shows ALERT without the overbar

### wiring-diagram-03
* shows green LED connected to RPi GPIO
* added the overbar to the ALERT function

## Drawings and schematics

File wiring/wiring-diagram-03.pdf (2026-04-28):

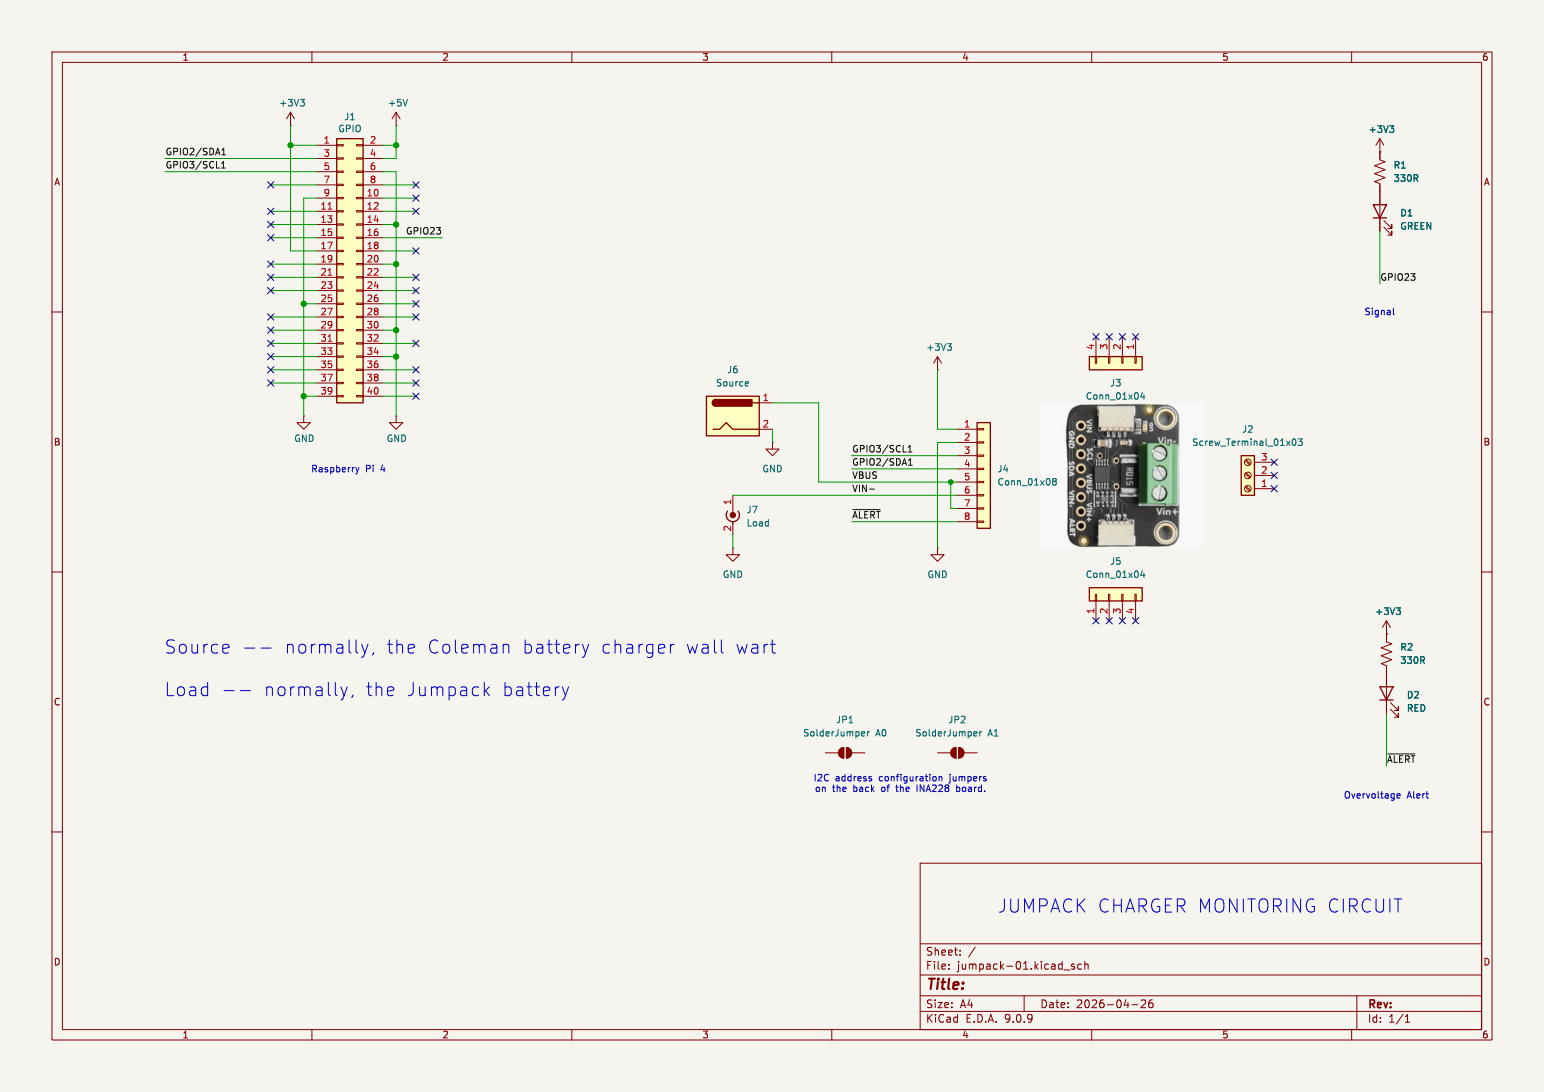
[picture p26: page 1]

JUMPACK CHARGER MONITORING CIRCUIT

Id: 1/1 Title: File: jumpack-01.kicad_sch Sheet: /

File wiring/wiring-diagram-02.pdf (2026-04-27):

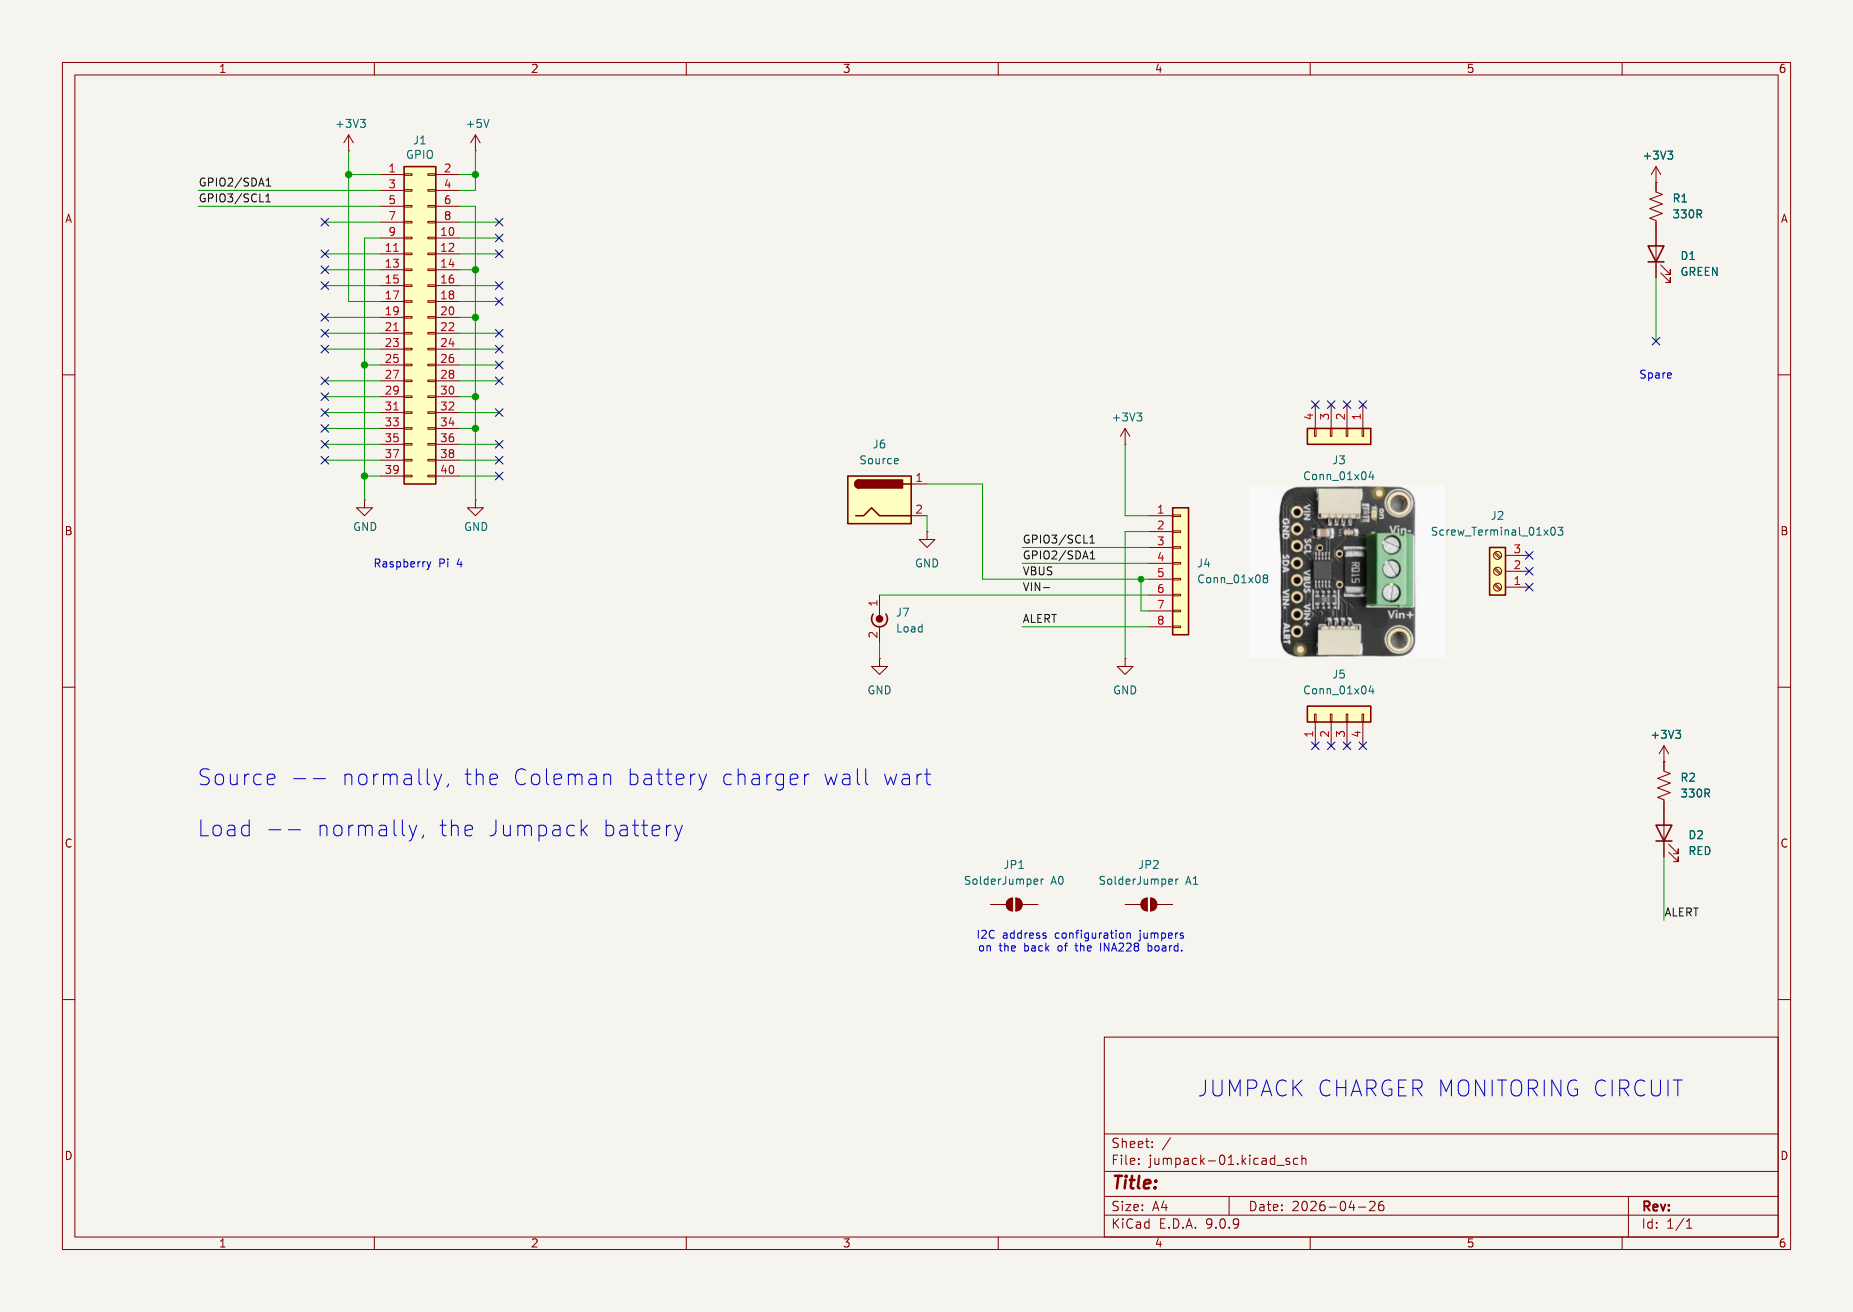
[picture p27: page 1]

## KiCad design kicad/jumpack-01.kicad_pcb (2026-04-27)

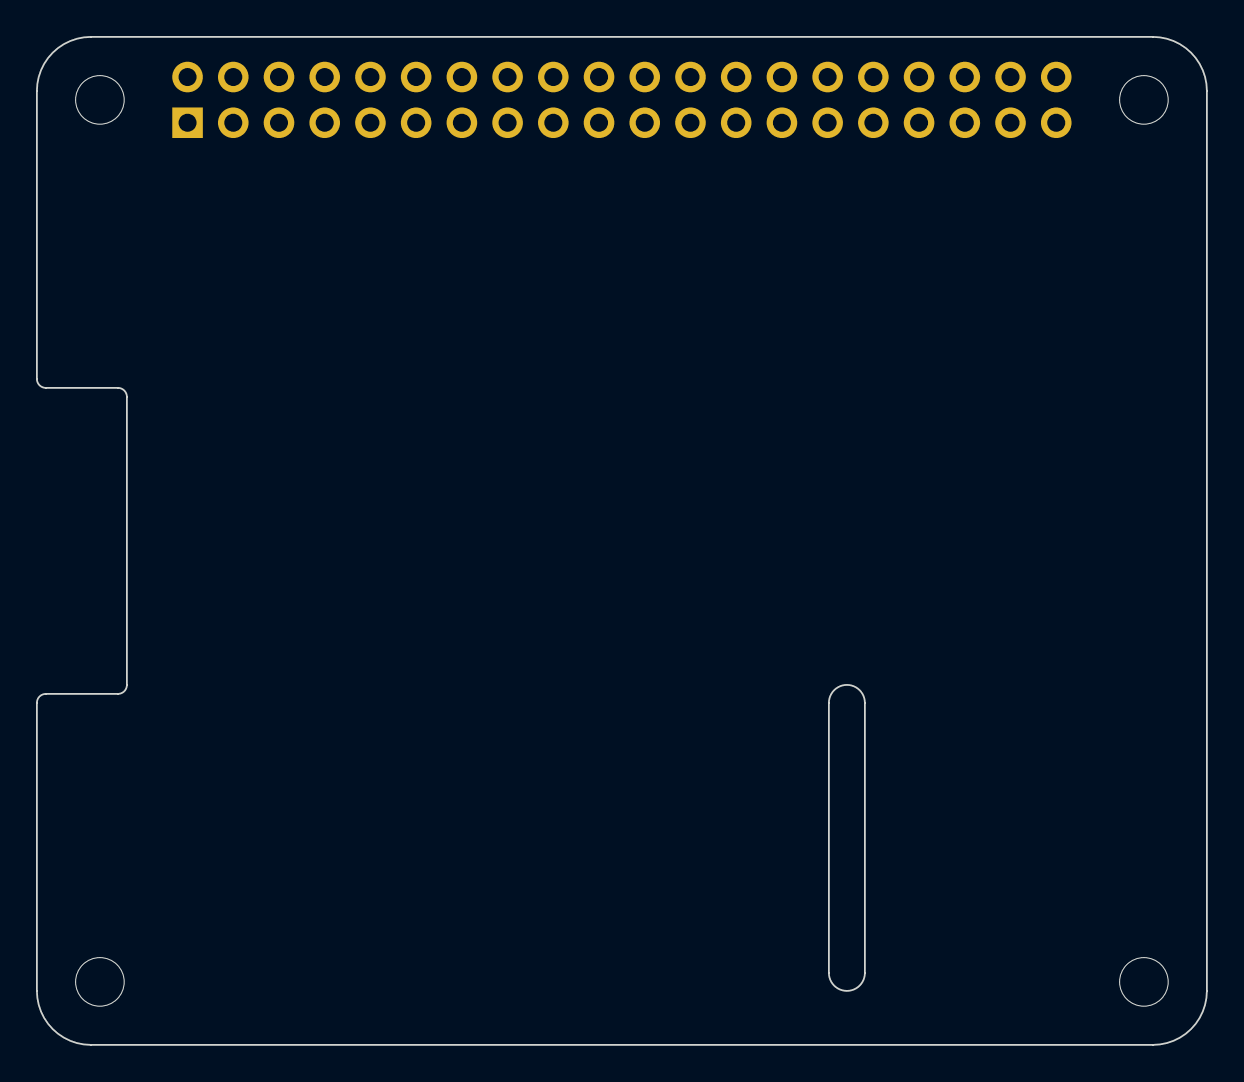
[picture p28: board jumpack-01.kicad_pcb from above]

Board: 2 copper layers, 65.0 x 56.0 mm, 5 parts (1 on the bottom side), 3 nets, no tracks yet.

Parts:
J1: GPIO; PinSocket_2x20_P2.54mm_Vertical
MH1, MH2, MH3, MH4: MountingHole_2.7mm_M2.5

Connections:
+3V3: J1.1, J1.17
+5V: J1.2, J1.4
GND: J1.6, J1.9, J1.14, J1.20, J1.25, J1.30, J1.34, J1.39

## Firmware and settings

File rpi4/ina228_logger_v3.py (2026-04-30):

#!/usr/bin/env python3

"""
INA228 Logger - Version 3
Logs INA228 power monitoring data to SQLite database
"""

import functools, sys, time
import argparse, os, signal
import sqlite3
from datetime import datetime
from pathlib import Path

try :
    import board
    import adafruit_ina228
    import RPi.GPIO as GPIO
except ModuleNotFoundError as e:
    print(f"Error: {e}")
    print(f"\nDid you `source ./.venv/bin/activate` into your virtual environment?\n")
    sys.exit(0)

# Configuration Constants
CONVERSION_TIME = 7      # 7 = 4120µs (maximum, best noise rejection)
AVERAGING_COUNT = 4      # 4 = 16 samples (2^4 = 16)
PID_FILE = "./ina228_logger.pid"
GREEN_LED = 23          # gpio pin 23 is physical pin 16

# Global flag for clean shutdown
shutdown_requested = False


def signal_handler(signum, frame):
    """Handle SIGTERM and SIGINT for clean shutdown"""
    global shutdown_requested
    shutdown_requested = True
    print("\nShutdown signal received, cleaning up...", file=sys.stderr)


def check_already_running():
    """Check if another instance is already running via PID file"""
    if os.path.exists(PID_FILE):
        try:
            with open(PID_FILE, 'r') as f:
                old_pid = int(f.read().strip())
 
            # Check if process is still running
            try:
                os.kill(old_pid, 0)  # Doesn't actually kill, just checks if process exists
                print(f"Error: Logger already running with PID {old_pid}", file=sys.stderr)
                print(f"If this is incorrect, remove {PID_FILE} and try again", file=sys.stderr)
                return False
            except OSError:
                # Process doesn't exist, stale PID file
                print(f"Removing stale PID file (PID {old_pid} not running)", file=sys.stderr)
                os.remove(PID_FILE)
        except (ValueError, IOError) as e:
            print(f"Warning: Could not read PID file: {e}", file=sys.stderr)
            os.remove(PID_FILE)
    
    # Write current PID
    with open(PID_FILE, 'w') as f:
        f.write(str(os.getpid()))
    
    return True


def remove_pid_file():
    """Remove PID file on clean exit"""
    try:
        if os.path.exists(PID_FILE):
            os.remove(PID_FILE)
    except Exception as e:
        print(f"Warning: Could not remove PID file: {e}", file=sys.stderr)


def create_database(db_path):
    """Create database with readings and metadata tables"""
    conn = sqlite3.connect(db_path)
    
    # Main readings table
    conn.execute("""
        CREATE TABLE IF NOT EXISTS readings (
            id INTEGER PRIMARY KEY AUTOINCREMENT,
            timestamp TEXT NOT NULL,
            current_a REAL,
            bus_voltage_v REAL,
            shunt_voltage_v REAL,
            power_w REAL,
            energy_j REAL,
            charge_c REAL,
            temperature_c REAL
        )
    """)
    
    # Metadata table
    conn.execute("""
        CREATE TABLE IF NOT EXISTS metadata (
            parameter_name TEXT PRIMARY KEY,
            parameter_value TEXT
        )
    """)
    
    conn.execute("PRAGMA journal_mode=WAL")
    conn.commit()
    return conn


def log_metadata(conn, ina228):
    """Log configuration and calibration metadata"""
    metadata = {
        'shunt_resistance_ohms': str(ina228.shunt_resistance),
        'current_lsb_a': str(ina228._current_lsb),
        'averaging_count': str(ina228.averaging_count),
        'adc_range': str(ina228.adc_range),
        'mode': str(ina228.mode),
        'bus_voltage_conv_time': str(ina228.bus_voltage_conv_time),
        'shunt_voltage_conv_time': str(ina228.shunt_voltage_conv_time),
        'temp_conv_time': str(ina228.temp_conv_time),
        'shunt_cal': str(ina228._shunt_cal),
        'device_id': str(ina228.device_id),
        'manufacturer_id': str(ina228._manufacturer_id)
    }
    
    for name, value in metadata.items():
        conn.execute(
            "INSERT OR REPLACE INTO metadata (parameter_name, parameter_value) VALUES (?, ?)",
            (name, value)
        )
    conn.commit()


def configure_ina228(ina228):
    """Configure INA228 for optimal performance"""
    # Set conversion times to maximum (4120µs) for best noise rejection
    ina228.bus_voltage_conv_time = CONVERSION_TIME
    ina228.shunt_voltage_conv_time = CONVERSION_TIME
    ina228.temp_conv_time = CONVERSION_TIME
    
    # Set averaging to 16 samples
    ina228.averaging_count = AVERAGING_COUNT


def log_reading(conn, ina228, verbose=False):
    """Read from INA228 and log to database"""
    # Get current timestamp
    timestamp = datetime.now().isoformat()
    
    # Read all measurements (library returns SI base units)
    current_a = ina228.current
    bus_voltage_v = ina228.bus_voltage
    shunt_voltage_v = ina228.shunt_voltage
    power_w = ina228.power
    energy_j = ina228.energy
    charge_c = ina228.charge
    temperature_c = ina228.die_temperature
    
    # Check for alert flags and warn to stderr
    flags = ina228.alert_flags
    active_alerts = [name for name, value in flags.items() if value and name not in ['CNVRF', 'MEMSTAT']]
    if active_alerts:
        print(f"WARNING [{timestamp}]: Active alerts: {', '.join(active_alerts)}", file=sys.stderr)
    
    # Insert into database
    conn.execute("""
        INSERT INTO readings 
        (timestamp, current_a, bus_voltage_v, shunt_voltage_v, 
         power_w, energy_j, charge_c, temperature_c)
        VALUES (?, ?, ?, ?, ?, ?, ?, ?)
    """, (timestamp, current_a, bus_voltage_v, shunt_voltage_v,
          power_w, energy_j, charge_c, temperature_c))
    conn.commit()
    
    # Print to stdout if verbose (convert to human-friendly units)
    if verbose:
        time_str = datetime.now().strftime('%Y-%m-%d %H:%M:%S')
        print(f"{time_str} | {bus_voltage_v:7.3f}V | {current_a*1000:8.2f}mA")


def main():
    global shutdown_requested

    # Set up the green LED
    state = False
    toggle = [ GPIO.HIGH, GPIO.LOW ]
    GPIO.setmode(GPIO.BCM)
    GPIO.setup(GREEN_LED, GPIO.OUT, initial=toggle[state])      # initially OFF
    state = not state
    GPIO.output(GREEN_LED, toggle[state])        # Pull low -> ON
    
    # Set up argument parser
    parser = argparse.ArgumentParser(description='INA228 Data Logger v2')
    parser.add_argument('-v', '--verbose', action='store_true',
                       help='Print readings to stdout')
    args = parser.parse_args()
    
    # Check if already running
    if not check_already_running():
        return 1
    
    # Register signal handlers
    signal.signal(signal.SIGTERM, signal_handler)
    signal.signal(signal.SIGINT, signal_handler)
    
    # Generate database filename with timestamp (no special chars)
    timestamp_str = datetime.now().strftime('%Y%m%d_%H%M%S')
    db_path = f"./databases/jumpack_{timestamp_str}.db"
    
    # Print startup message
    print(f"Logger started, database: {db_path}")
    if args.verbose:
        print("Verbose mode enabled")
    
    # Initialize I2C and INA228
    try:
        i2c = board.I2C()
        ina228 = adafruit_ina228.INA228(i2c)
        ina228._alert_conv = False
    except Exception as e:
        print(f"Failed to initialize INA228: {e}", file=sys.stderr)
        remove_pid_file()
        return 1
    
    # Configure INA228 for optimal settings
    try:
        configure_ina228(ina228)
        if args.verbose:
            print(f"INA228 configured: {AVERAGING_COUNT} samples @ {4120}µs conversion time")
    except Exception as e:
        print(f"Failed to configure INA228: {e}", file=sys.stderr)
        remove_pid_file()
        return 1
    
    # Create database
    try:
        conn = create_database(db_path)
        log_metadata(conn, ina228)
    except Exception as e:
        print(f"Failed to create database: {e}", file=sys.stderr)
        remove_pid_file()
        return 1
    
    # Main logging loop
    try:
        while not shutdown_requested:
            time.sleep(2.0)
            log_reading(conn, ina228, verbose=args.verbose)
    except Exception as e:
        print(f"Error in logging loop: {e}", file=sys.stderr)
    finally:
        # Clean shutdown
        conn.execute("PRAGMA wal_checkpoint(TRUNCATE)")
        conn.close()
        remove_pid_file()
        GPIO.output(GREEN_LED, toggle[False])
        GPIO.cleanup()
        print(f"Logger stopped, database closed: {db_path}")
    
    return 0


if __name__ == "__main__":
    print = functools.partial(print, flush=True)
    sys.exit(main())

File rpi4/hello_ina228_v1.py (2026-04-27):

#!/usr/bin/env python3

"""
Hello INA228 - Basic Power Monitoring Script
Reads voltage, current, power, and temperature from INA228
"""

import time
import board
import adafruit_ina228

def main():
    print("=" * 60)
    print("Hello INA228 - Power Monitor Test")
    print("=" * 60)

    # Initialize I2C bus
    try:
        i2c = board.I2C()
        print("✓ I2C bus initialized")
    except Exception as e:
        print(f"✗ Failed to initialize I2C: {e}")
        return

    # Initialize INA228 sensor
    try:
        ina228 = adafruit_ina228.INA228(i2c)
        print("✓ INA228 detected at address 0x40")
        ina228._alert_conv = False
    except Exception as e:
        print(f"✗ Failed to detect INA228: {e}")
        print("  Check wiring and run 'sudo i2cdetect -y 1'")
        return

    # Configure the sensor
    # Shunt resistor: 15 milliohms (0.015 ohms)
    # Max expected current: 600mA (0.6A)
    print("\nConfiguration:")
    print(f"  Shunt resistor: 15 mΩ (0.015 Ω)")
    print(f"  Max current: 600 mA")
    print(f"  Bus conversion time: {ina228.bus_voltage_conv_time} µs")
    print(f"  Shunt conversion time: {ina228.shunt_voltage_conv_time} µs")
    print(f"  Averaging count: {ina228.averaging_count}")
    
    print("\n" + "=" * 60)
    print("Starting continuous measurements (Ctrl+C to stop)")
    print("=" * 60)
    print()
    
    # Continuous measurement loop
    try:
        while True:
            # Wait 2 seconds before next reading
            time.sleep(2)

            # Read all measurements
            current_ma = ina228.current * 1000
            bus_voltage = ina228.bus_voltage
            shunt_voltage_mv = ina228.shunt_voltage * 1000  # Convert V to mV
            power_mw = ina228.power * 1000
            energy_j = ina228.energy
            temp_c = ina228.die_temperature
            
            # Display results
            print(f"Timestamp: {time.strftime('%Y-%m-%d %H:%M:%S')}")
            print(f"  Current:       {current_ma:8.2f} mA")
            print(f"  Bus Voltage:   {bus_voltage:8.3f} V")
            print(f"  Shunt Voltage: {shunt_voltage_mv:8.3f} mV")
            print(f"  Power:         {power_mw:8.2f} mW")
            print(f"  Energy:        {energy_j:8.2f} J")
            print(f"  Temperature:   {temp_c:8.2f} °C")
            print("-" * 60)

    except KeyboardInterrupt:
        print("\n\nMeasurement stopped by user")
        # Optional: Put INA228 into shutdown mode to save power
        ina228.mode = adafruit_ina228.Mode.SHUTDOWN
        print("=" * 60)

if __name__ == "__main__":
    main()

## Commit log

2026-04-28 initial draft of logger-v3; update docs, wiring
    [jumpack-01.kicad_sch]
2026-04-30 added functools to properly include flush=True for all print()'s
2026-05-17 README.md updated to indicate some of the python scripts run on an RPi4 and other python scripts are intended to run on an x86 desktop.
    Python scripts that `import board` to read the INA228 breakout board
    were moved to a new directory, ./rpi4
    Python scripts that are intended to run on the x86 computer were moved
    to a new directory, ./x86.
